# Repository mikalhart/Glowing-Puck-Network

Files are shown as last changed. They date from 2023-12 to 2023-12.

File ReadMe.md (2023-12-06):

# The Glowing Puck

Glowing Pucks are coaster-sized art objects ostensibly built to decorate tables at a celebration dinner, but with a few surprises for the guests.  They are small, circular resin creations made of dried English wildflowers embedded in an epoxy disc, encased in a 3D-printed shell.

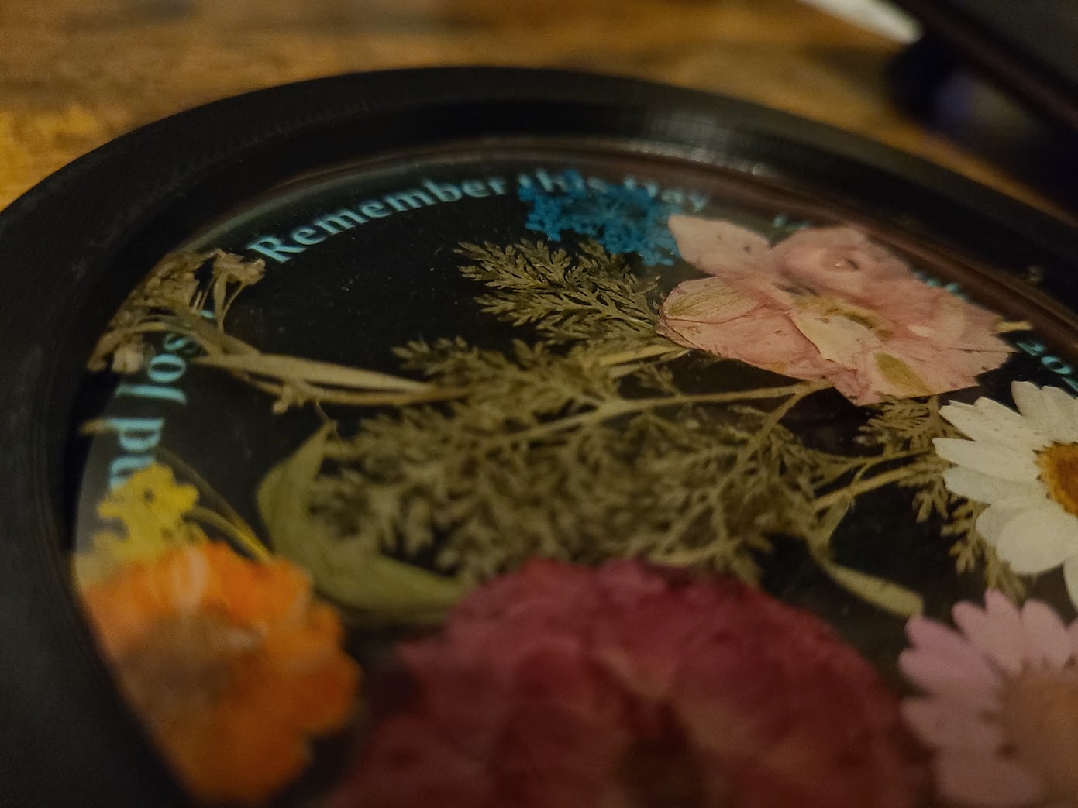
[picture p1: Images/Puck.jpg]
Pre-glow Puck


## A Surprise

At a 'significant moment' in the dinner (e.g. when bride and groom reappear), the Pucks around the room mysteriously begin to glow: first one... then two... then eventually all of them.  Soon the whole room is illuminated with bright, colorful swirling light!

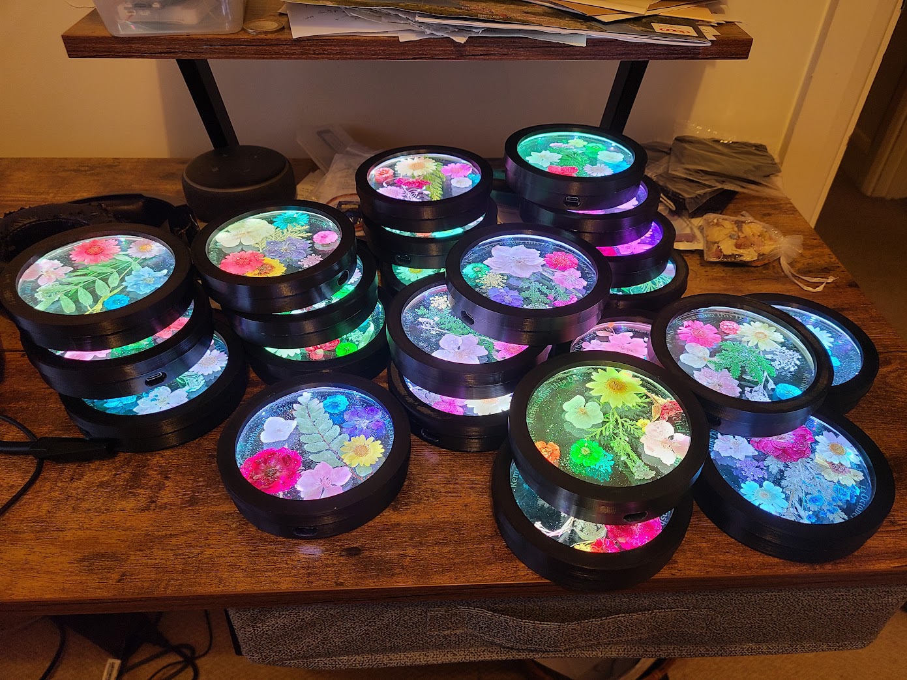
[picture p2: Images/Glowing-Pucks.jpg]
Glowing Pucks


## The Glow Explained

A speaker suddenly stands.  She explains to the murmuring guests that the Glow is intended to symbolize the love and support we share for the new couple on the threshold of their married life.  It celebrates that we are a loving people who came together on this memorable day to wish them happiness.

## A New Surprise: More Glows to Come

As the dinner progresses the Pucks continue to Glow cheerily, but eventually they fade and resume their inert state. The speaker rises once again.  The initial phase has ended, she explains. In preparation for the next, we are to take our Pucks home, join them to our house WiFi, and place them in a prominent location.

We learn that each of us has been granted the power to recreate the wedding Glow by touching two brass discs hidden on the Puck's underside.  A so-activated Puck sends a quiet invitation to its siblings around the world to join in a new Glow. Touching the brass discs triggers a global chorus of light and remembrance.

It's a beautiful way for us to commemorate the wedding and keep its memory fresh and alive.  It's how we'll reach out and say, "we remember you, and we remember this day!"

## One Final Surprise

The Pucks have one more surprise in store.  Every year on the date of the wedding anniversary, they perform a special celebration Glow that lasts the **entire day**.

## Theory of Operation

### At the Dinner

The Pucks are built to operate in two different modes.  As table ornaments, they are mostly asleep/inert, running off battery power and invisibly awakening every minute to check for special instructions.

At the predetermined time, the speaker (or someone in the audience) quietly enables a special 2.4GHz "Hot Spot" on her smartphone.  This is the signal to begin.  When the Pucks detect the new WiFi SSID **wedding-fireworks**, they start the spectacular celebration Glow.

The Pucks Glow for as long as that special WiFi SSID is enabled.  Once it disappears, they resume their semi-dormant state.

### At Home

After the Pucks have been distributed to their new homes, they must be connected to WiFi to sync with the 'Glow network'.  At this point they will be kept more or less always plugged in.

Teaching a Puck its new home's WiFi credentials involves putting it into "WiFi Training Mode" and configuring it with a cell phone or tablet. Instructions can be found in the [WiFi Training](WiFi-Training.md) document.

Once set up, a Puck at home wakes whenever its brass discs are touched.  This triggers a glow that cascades around the world, with a limit of one activation per Puck per day.

A Puck at home also wakes each minute to check whether any other Puck on the network has activated a Glow.  If so, it joins in!

## Build Guide

If you'd like to build your own Glow Pucks, consult the [Build Guide](Build-Guide.md).

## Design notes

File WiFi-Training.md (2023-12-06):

# Instructions for connecting the Puck to WiFi

To join the Glow network, each Puck must connect to its new owner's WiFi. It's probably best to provide the guests an instruction sheet when you hand them out, explaining how this is done.

## WiFi Training Instructions

At home, plug your new Puck in and teach it how to connect to your WiFi by putting it into **WiFi Training Mode**.

1. Gently press and hold the two brass discs for about six seconds.  Release when the Puck begins to pulse blue.

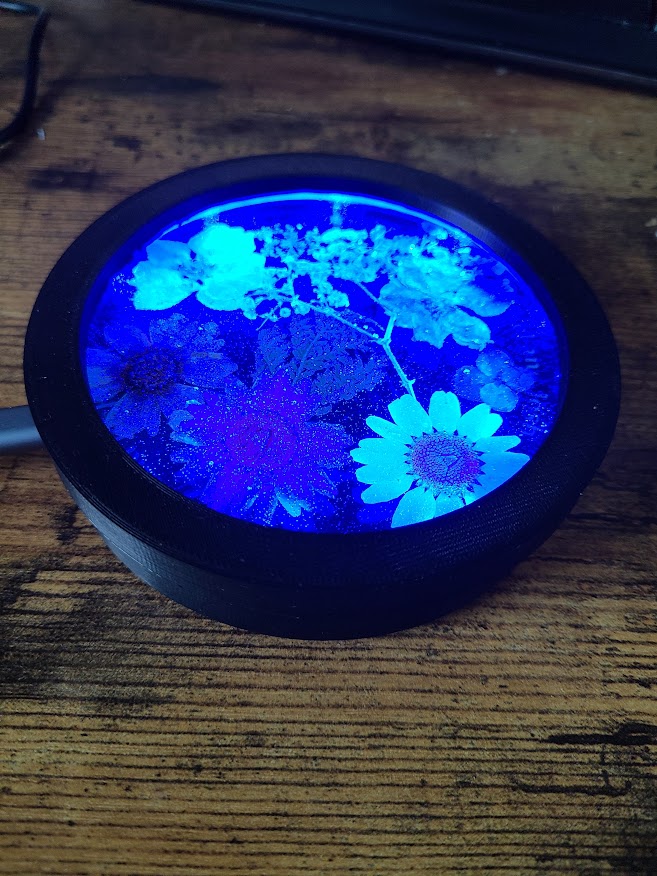
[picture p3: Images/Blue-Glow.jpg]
Blue Glow
    

1. On your phone or tablet, hunt for the newly-created WiFi network **Wedding-Puck**.  Connect to it.  (This network isn't connected to the internet, and on certain phones you may have to acknowledge that fact.)

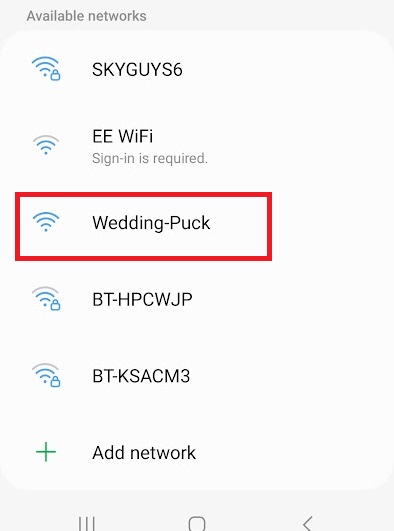
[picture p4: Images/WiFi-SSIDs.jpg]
WiFi SSIDs
    

1. In your phone's camera app, scan the QR code below, or simply open a browser and type <http://192.168.4.1> in the URL bar.

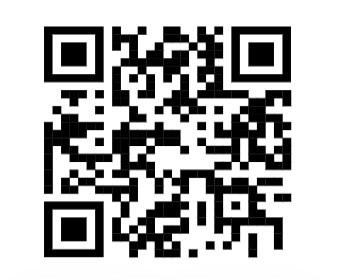
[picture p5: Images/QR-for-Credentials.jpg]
QR for Credentials
    

1. This brings up a page where you can enter your WiFi credentials. Fill in the page with your home WiFi name (SSID) and password and press **Submit**.  The Puck will store this info to connect to your WiFi.

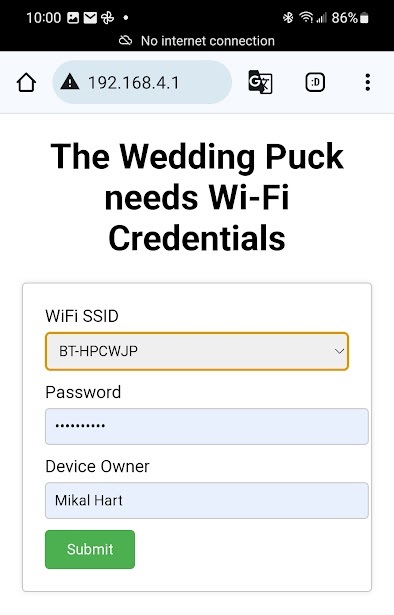
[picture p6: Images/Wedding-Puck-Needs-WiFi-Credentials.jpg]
Enter Credentials
    

At this point, WiFi Training ends, and your Puck is connected.  (It may immediately begin a celebration Glow in recognition that someone else has previously activated theirs.)

Keep your Puck plugged in.  Repeat steps 1-5 if you change location or WiFi credentials.

Whenever your Puck is dark, activate your own Glow by gently touching the two brass discs.

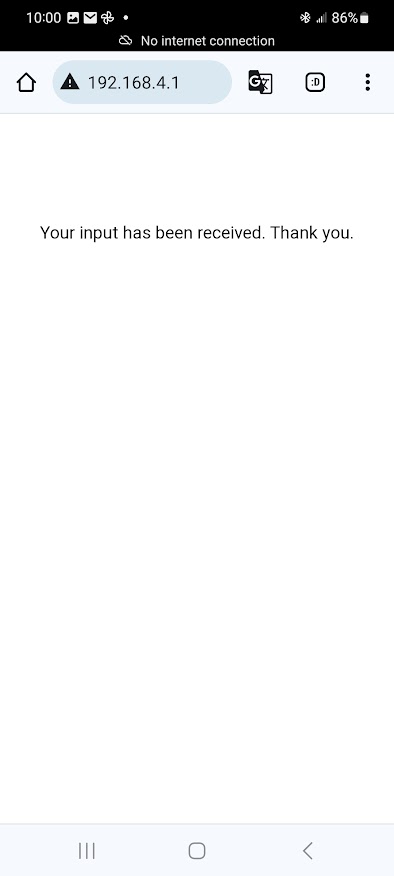
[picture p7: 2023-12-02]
Images/Your-Input-Has-Been-Received.jpg

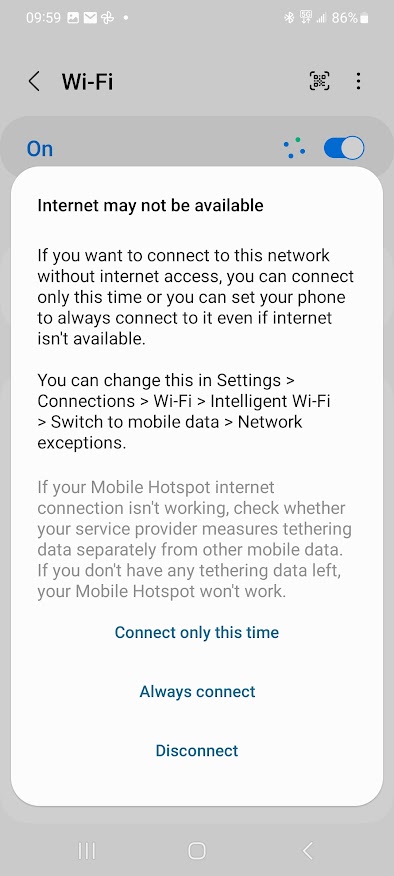
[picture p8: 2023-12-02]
Images/Internet-May-Not-Be-Available.jpg

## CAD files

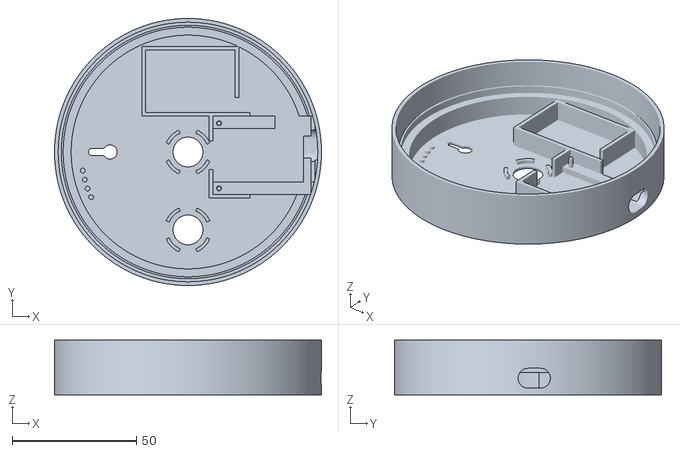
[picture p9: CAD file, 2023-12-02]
Collateral/Case-bottom.stl
107.4 x 107.4 x 22.0

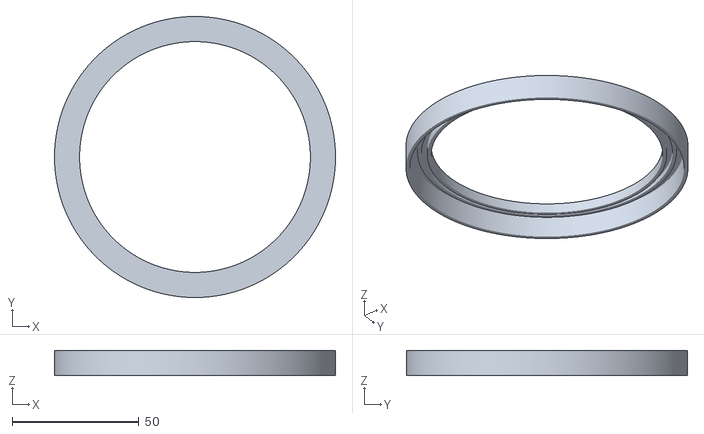
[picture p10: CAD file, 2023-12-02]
Collateral/Case-top.stl
110.8 x 110.8 x 10.0

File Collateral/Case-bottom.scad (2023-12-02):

use <Case-modules.scad>
Bottom();

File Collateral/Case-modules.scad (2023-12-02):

$fa = 1;
$fs = 0.5;
VERSION = 4;
TOPVERSION = 2;
WALL = 1.5;
DEPTHBASE = 1;
COASTERDIAM = 100;
LEDBANDTHICKNESS = 2;
FUDGE = 0.2;
USB_OFF_FROM_CENTER = 3.8;
USB_RECESS = 4;
USB_WIDTH = 9;
USB_HEIGHT = 7.6;
USB_DEPTH = 2;
DEPTHBATTERY = 9;
DEPTHSHIELD = 4;
PLATFORMDEPTH = 3.5;
PCBTHICKNESS = 2.2;
BOARDWALLDEPTH = 9; // 10; // high enough to hold the board, support coaster
LEDBANDWIDTH = 13;
LEDRETAINERDEPTH = BOARDWALLDEPTH + 3;
RIMWALLDEPTH = BOARDWALLDEPTH + LEDBANDWIDTH;

TOPRIMWALLDEPTH = 10;
SPECIALOFFSET = 2.5; // A northward bias for the compartments and USB hole to avoid leaks

D0 = COASTERDIAM - 4 * WALL;    // inside the edge of the coaster
DZ = D0 - 3;                    // inside-most rim of lid
D1 = COASTERDIAM + 2 * FUDGE;   // just outside the edge of the coaster
D1a = D1 + WALL;                // coaster retainer goes from D1 to D1a
D2 = D1 + 2 * LEDBANDTHICKNESS; // outside LEDs, inside of exterior wall
D3 = D2 + 2 * WALL;             // outside exterior wall
D4 = D3 + 2 * FUDGE;            // inside lid wall
D5 = D4 + 2 * WALL;             // outside lid wall

module Bottom()
{
  difference()
  {
    union()
    {
      BottomBase();
      compartments();
      difference() { supportrim(); compartments(true); }
      difference() { outerwall(); compartments(true); }
    }
    USBHole();
  }
}

module Top()
{
  translate([0, 0, 40])
  rotate([0, 180, 0])
  {
    color("red") topouterwall();
    color("green") topinnerwall1();
    color("purple") topinnerwall2();
    color("yellow") topflattop();
    // topstackingwall(); 
  }
}

module BottomBase()
{
  difference() 
  { 
    cylinder(h=DEPTHBASE, d = D3); 
    MountingHole(DEPTHBASE); 
    brassbutton(-D0/3, 0, 90, true);
    brassbutton(0, 0, 0, true);
  } // floor

  brassbutton(-D0/3, 0, 90, false);
  brassbutton(0, 0, 0, false);

  // Version indicators
  for (i=[1:VERSION])
    rotate([0, 0, 185 + 5 * i])
      translate([D0 / 2 - 4, 0, 0])
        cylinder(h=DEPTHBASE + 1, d = 2);
}

module pieSlice(a, r, h)
{
  // a:angle, r:radius, h:height
  rotate_extrude(angle=a) square([r,h]);
}

module brassbutton(x, y, angle, negative = false)
{
  BRASSDIAM = 16;
  BRASSDEPTH = 1;
  LIPWIDTH = 2;
  BRACKETDEPTH = 2.5;
  rotate([0, 0, angle])
  translate([x, y, 0])
  {
    if (negative)
    {
      cylinder(h=BRACKETDEPTH, d=BRASSDIAM - 2 * LIPWIDTH);
    }
    else
    {
      difference()
      {
        cylinder(h=BRACKETDEPTH, d=BRASSDIAM+2*WALL);
        cylinder(h=BRACKETDEPTH, d=BRASSDIAM+2*FUDGE);
        for (i=[0:90:270])
        rotate([0, 0, i-45/2])
          pieSlice(45, BRASSDIAM+2*WALL, BRACKETDEPTH);
      }
    }
  }
}

LIPDEPTH = 2.5; // for stacking coasters
module topouterwall()
{
  difference()
  {
    cylinder(h=TOPRIMWALLDEPTH, d = D5);
    
    // We'll make the removed cylinder taper slightly inward
    cylinder(h=TOPRIMWALLDEPTH+0.1, d1 = D4 - 2 * FUDGE, d2 = D4);
  }
}

// Not used
module topstackingwall()
{
  translate([0, 0, -LIPDEPTH])
  difference()
  {
    cylinder(h=LIPDEPTH, d = D5);
    cylinder(h=LIPDEPTH, d = D4);
  }
}

INNERWALLDEPTH1 = 2;
INNERWALLDEPTH2 = 3;
module topinnerwall1()
{
  OUTER = D1a - FUDGE;
  INNER = OUTER - 2 * WALL;
  DEPTH = DEPTHBASE + INNERWALLDEPTH1;
  difference()
  {
    cylinder(h=DEPTH, d = OUTER);
    cylinder(h=DEPTH+0.1, d = INNER);
  }
}

module topinnerwall2()
{
  OUTER = D0;
  INNER = DZ;
  DEPTH = DEPTHBASE + INNERWALLDEPTH2;
  difference()
  {
    cylinder(h=DEPTH, d = OUTER);
    cylinder(h=DEPTH+0.1, d = INNER);
  }
}

module topflattop()
{
  difference()
  {
    cylinder(h=DEPTHBASE, d = D5);
    cylinder(h=DEPTHBASE+0.1, d = DZ);
  }
  DEP = 1;
  DIA = 2;
  if (0) for (i=[1, TOPVERSION])
  {
    rotate([0, 0, 180 + 5 * i])
    translate([(D5 + D0) / 4, 0, -DEP])
    cylinder(h = DEP, d = DIA);
  }
}

module outerwall()
{
  difference()
  {
    cylinder(h=RIMWALLDEPTH, d = D3);
    cylinder(h=RIMWALLDEPTH, d = D2);
  }
}

// Shelf that supports coaster and brackets it
module supportrim()
{
  difference()
  {
    cylinder(h=BOARDWALLDEPTH, d = D2);
    cylinder(h=BOARDWALLDEPTH, d = D0);
  }

  // LED retainer
  difference()
  {
    cylinder(h=LEDRETAINERDEPTH, d = D1a);
    cylinder(h=LEDRETAINERDEPTH, d = D1);
  }
}

module compartments(negative = false)
{
  BOARDWIDTH = 39.5; // 39.1; // 40.1;
  BOARDHEIGHT = 31.5;
  CONNECTORWIDTH = 8;

  PILLAROFFSETX = 2.5;
  PILLAROFFSETY1 = 2.4;
  PILLAROFFSETY2 = 2.9;
  PILLARDIAMTOP = 1.7; // 1.7;
  PILLARDIAMBASE = 2.0; // 1.7;
  PILLARDEPTH = 4.0; // 3.0;

  BATTERYWIDTH = 36.0; // 37.0; // 38.0;
  BATTERYHEIGHT = 25.0; // 25.5; // 26.0;
  BATTERYDEPTH = 8;

  CABLEEXTRA = 27;
  CABLEWIDTH = 6;

  RWALL = D1 / 2 - .7;
  x0 = RWALL - BOARDWIDTH - WALL;
  x1 = x0 + WALL;
  x1a = x1 + 15;
  x2 = x1 + 25;
  x3 = RWALL;
  x4 = x3 + WALL;
  
  y0 = -BOARDHEIGHT / 2 - USB_OFF_FROM_CENTER - WALL + SPECIALOFFSET;
  y1 = y0 + WALL;
  y3 = BOARDHEIGHT / 2 - USB_OFF_FROM_CENTER + SPECIALOFFSET;
  y2 = y3 - CONNECTORWIDTH;
  y4 = y3 + WALL;
  
  a0 = x0 - CABLEEXTRA;
  a1 = a0 + WALL;
  a2 = a1 + BATTERYWIDTH;
  a3 = a2 + WALL;
  
  b0 = y3;
  b1 = b0 + WALL;
  b2 = b1 + BATTERYHEIGHT;
  b3 = b2 + WALL;

  if (negative)
  {
    translate([x1, y1, 0])
      cube([x3-x1, y3-y1, LEDRETAINERDEPTH]);
    SWITCHOFFSET = 5;
    translate([x3, y1 + SWITCHOFFSET, 0])
      cube([x4-x3, y3-y1-SWITCHOFFSET, LEDRETAINERDEPTH]);
  }
  else
  intersection()
  {
    union()
    {
      // Board stuff
      translate([x0, y3-10, 0]) // top of left wall
        cube([x1-x0, 10, BOARDWALLDEPTH]);
      translate([x0, y1, 0]) // bottom of left wall
        cube([x1-x0, 10, BOARDWALLDEPTH]);
      translate([x0, y0, 0]) // bottom wall
        cube([x1a-x0, y1-y0, BOARDWALLDEPTH]);
      translate([x0, y3, 0]) // top wall
        cube([x1a-x0, y4-y3, BOARDWALLDEPTH]);
      translate([x3, y0, 0]) // right wall
        cube([x4-x3, y4-y0, PLATFORMDEPTH + PCBTHICKNESS/*BOARDWALLDEPTH*/]);

      translate([x1, y3-5, 0]) // platform 1 (upper left)
        cube([x2-x1, 5, PLATFORMDEPTH]);
      translate([x1, y1, 0]) // platform 2 (lower left)
        cube([x3-x1, 5, PLATFORMDEPTH]);
      translate([x3-3, y1, 0]) // platform 3 (right)
        cube([3, y2 - y1, PLATFORMDEPTH]);
      translate([x1 + PILLAROFFSETX, y1 + PILLAROFFSETY1, PLATFORMDEPTH]) // pillar 1
        cylinder(h = PILLARDEPTH, d1 = PILLARDIAMBASE, d2 = PILLARDIAMTOP);
      translate([x1 + PILLAROFFSETX, y3 - PILLAROFFSETY2, PLATFORMDEPTH]) // pillar 2
        cylinder(h = PILLARDEPTH, d1 = PILLARDIAMBASE, d2 = PILLARDIAMTOP);
      
      // Battery stuff
      translate([a0, b0, 0]) // left wall
        cube([a1-a0, b3-b0, BOARDWALLDEPTH]);
      translate([a0, b0, 0]) // bottom wall
        cube([a3-a0, b1-b0, BOARDWALLDEPTH]);
      translate([a0, b2, 0]) // top wall
        cube([a3-a0, b3-b2, BOARDWALLDEPTH]);
      translate([a2, b1 + CABLEWIDTH, 0]) // right wall
        cube([a3-a2, b3-(b1 + CABLEWIDTH), BOARDWALLDEPTH]);
    }
    cylinder(h=BOARDWALLDEPTH, d = D3);
  }
}

module USBHole()
{
  USB_HOLE_WIDTH = USB_WIDTH + 2 * 2;
  USB_HOLE_HEIGHT = USB_HEIGHT + 2 * 3 + WALL;
  USB_HOLE_DEPTH = USB_DEPTH + 2 * 2 + 2;
  RWALL = COASTERDIAM / 2;

  translate([RWALL - USB_HOLE_HEIGHT/2 + 0.2, 0 - USB_HOLE_WIDTH / 2 + SPECIALOFFSET, PLATFORMDEPTH + PCBTHICKNESS + USB_DEPTH / 2 - USB_HOLE_DEPTH / 2/*USB_DEPTH / 2 */])
  rotate([0, 0, 90])
  rotate([90, 0, 0])
  union()
  {
      RADIUS = USB_HOLE_DEPTH / 2;
      translate([RADIUS, RADIUS, 0])
          cylinder(h = USB_HOLE_HEIGHT, d = USB_HOLE_DEPTH);
      translate([RADIUS, 0, 0]) 
          cube([USB_HOLE_WIDTH - USB_HOLE_DEPTH, USB_HOLE_DEPTH, USB_HOLE_HEIGHT], false);
      translate([USB_HOLE_WIDTH - USB_HOLE_DEPTH + RADIUS, RADIUS, 0])
          cylinder(h = USB_HOLE_HEIGHT, d = USB_HOLE_DEPTH);
  }
}

module MountingHole(depth)
{
  HEAD4DIAM = 5.48;
  SHAFT4DIAM = 2.74;

  BIGDIAM = HEAD4DIAM + FUDGE;
  LITTLEDIAM = SHAFT4DIAM + FUDGE;

  translate([-D0/3, 0, 0])
  rotate([0, 0, 90])
  {
    cylinder(depth, d = BIGDIAM);
    translate([-LITTLEDIAM / 2, 0, 0]) 
      cube([LITTLEDIAM, BIGDIAM/2 + 3 * LITTLEDIAM / 2, depth], center = false);
    translate([0, BIGDIAM/2 + 3 * LITTLEDIAM / 2, 0])
      cylinder(depth, d = LITTLEDIAM);
  }
}

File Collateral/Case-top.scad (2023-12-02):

use <Case-modules.scad>
Top();

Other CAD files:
Collateral/Case.scad

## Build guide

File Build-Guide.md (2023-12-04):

# Building Your Own Glowing Pucks

It's not too hard to build your own Glowing Pucks.  There's very little electronic assembly: only 5 wires to be soldered.  No small-pitch stuff.

The Puck shell needs to be 3D printed.  Other than that, the hardware assembly is trivial.

Software install shouldn't be too tricky for anyone who has done any Arduino programming, though you'll need to get a (free) account at HiveMQ to support the MQTT traffic.  Other MQTT brokers would probably work fine as well.

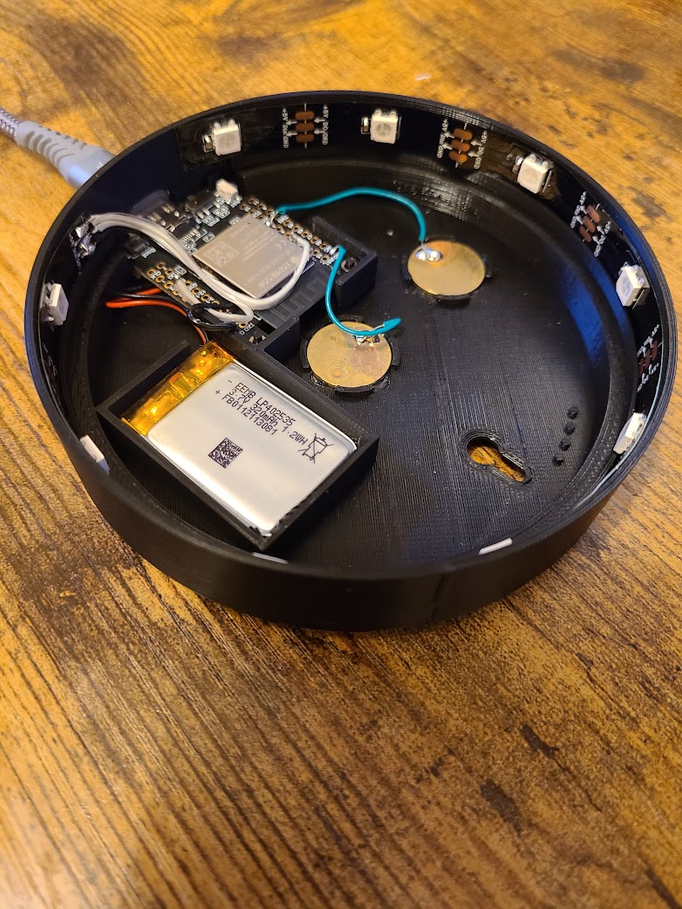
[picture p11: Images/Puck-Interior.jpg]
The interior of a Puck


## Materials

You'll need to procure a handful of inexpensive electronic and hardware items to build this project.

### Electronic Components

- LilyGo ESP32 [T7-S3 Development Board](https://www.lilygo.cc/products/t7-s3) - the brains behind the device
- 9 [WS2812-B LEDs](https://www.aliexpress.com/item/2036819167.html) in 30/meter spacing - these are embedded in the shell and illuminate the epoxy coaster from the side
- 2 16mm [brass stamping blanks](https://www.aliexpress.com/item/32716955260.html) - the touch "buttons" that turn the device on
- 320mah [402535 LiPo Battery](https://www.amazon.co.uk/dp/B08HD1N273) - **WARNING: The 1.2mm connector needs polarity reversal**
- 3-wire [ribbon cable](https://www.amazon.co.uk/dp/B09R42ZGQD) - to connect the microcontroller to the LED strip
- 2 26-gauge [solid-core wires](https://www.amazon.co.uk/sourcing-map-Electrical-High-Temperature-Manipulator/dp/B0C6FDQ6K9) - to connect the brass discs to the microcontroller
- [USB-C Cable](https://www.amazon.co.uk/dp/B0BPH67J4X) - for charging the device

### Hardware Components

- 3D-printed Coaster [lid](Collateral/Case-top.stl) and [base](Collateral/Case-bottom.stl).  (SCAD source: [lid](Collateral/Case-top.scad), [base](Collateral/Case-bottom.scad))
- 10cm diam x 1cm deep Epoxy Coaster - I love [these](https://www.etsy.com/uk/listing/1048533995/purple-floral-handmade-resin-coasters?variation0=2108656922), but any clear coaster with these dimensions should do
- 10cm diameter background [background](Collateral/Puck-Background.png) ([svg](Collateral/Puck-Background.svg))
- 4 stick-on [rubber feet](https://www.amazon.co.uk/gp/product/B08QHZ1SW4)

### Software Components

- [Wedding-Puck.ino](Wedding-Puck.ino) Arduino sketch
- Several Arduino Libraries
  - [Adafruit NeoPixel](https://github.com/adafruit/Adafruit_NeoPixel) - to drive the LEDs
  - WiFiClientSecure (built-in) - for interacting with MQTT broker
  - [PubSubClient](https://github.com/knolleary/pubsubclient) - for interacting with MQTT broker
  - [ESPAsyncWebServer](https://github.com/me-no-dev/ESPAsyncWebServer) - for WiFi Training mode
  - [AsyncTCP](https://github.com/dvarrel/AsyncTCP) - for WiFi Training mode
  - [ArduinoJson](https://github.com/bblanchon/ArduinoJson) - for saving WiFi credentials

## Assembling the Electronics

1. **Cut LED strip**.  Cut a strip of 9 LEDs from the WS2812B roll.  At 30/meter spacing, this gives just about the right length to surround the 10cm diameter coaster.

1. **Solder LED Strip**.  Cut and strip about 6cm of the ribbon cable.  Solder one end of the ribbon cable to the 3 inputs om the LED strip and the other end to the LilyGo T7-S3 as follows:

    - **LED GND** <--> **T7 GND**
    - **LED +5V** <--> **T7 +5V**
    - **LED Din** <--> **T7 pin 18**

1. **Solder Brass Discs**. Cut and strip about 3-4cm of the solid-core wire.  Solder one end of each wire to a brass disc.  You'll have to apply the iron for a long time to get the discs hot enough to properly bond with the solder.  Be careful!  Don't burn yourself on the hot disc!  Solder one wire to T7 GND and the other to the T7 touch pin 5.

    - **Centre Brass Disc** <--> **T7 GND**
    - **Edge Brass Disc** <----> **T7 pin 5**

1. **Hook up battery**.  Insert the battery into the T7 connectoor.  **NOTE**: If you buy the variant of the [402535 LiPo battery](https://www.amazon.co.uk/dp/B08HD1N273) that I sourced on [Amazon](https://www.amazon.co.uk/dp/B08HD1N273), it is the **WRONG POLARITY**.  You'll need to make an easy [polarity adjustment](https://youtu.be/za-azgbZor8?si=B9gw-FfFPbaVmNWF) before you use it with the T7-S3.  Make **sure** the battery's red wire matches up with the **+** terminal on the T7.

## Assembling the Hardware

1. **Print Case**.  Print the [top](Collateral/Case-top.stl) and [bottom](Collateral/Case-bottom.stl) coaster shells.  I've had good luck with black PLA, but I imagine any material would do.

1. **Mount Circuitry**. Snap the T7 and the battery into their respective compartments in the shell base.

1. **Mount LED strip**. Insert the LED strip into its grooved slot around the perimeter of the base, with the LEDs facing inward.  No need to remove the adhesive on the back of the strip: it's not going anywhere.  The epoxy coaster and the assembly will keep it firmly in place.

1. **Glue Discs**. Apply a bit of super glue - I find the gel variant works great - around the rim of the round compartments on the bottom, and glue the brass discs into place.

1. **Create Backdrop**.  Cut a 10cm circle from a bit of black paper or cardstock to use as a backdrop.  You'll insert it into the shell base, underneath the epoxy coaster.  Optionally, draw a design in gold or coloured pen that can be seen through the transparent bits.  (I created a [design](Collateral/Puck-Background.png) in Inkscape that I printed on a 5x7" photo printer.  This worked rather well.)
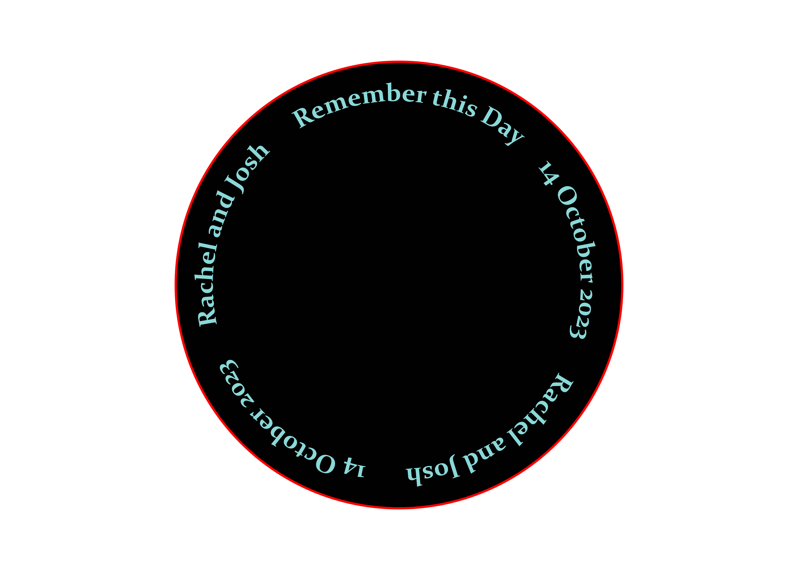
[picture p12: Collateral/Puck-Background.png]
Puck Backdrop


1. **Install Software and Test**. Before you permanently glue down the electronics, now would be a good time to install the software components and test the hardware, in case you need to do any rework.

1. **Hot Glue Components**.  Apply just enough glue to hold the T7 and battery firmly in place.  Hot glue works great here.  Put some on the brass discs, too, to help stabilize them.

1. **Insert Backdrop and Coaster**. Insert the backdrop and the epoxy coaster into the assembly.  If the coaster is not perfectly round, you may have to use a small screwdriver to pry it into place.

1. **Finish Assembly**. Press the shell lid down onto the assembly.  It's tapered to have a reasonably nice press fit, but you might consider applying a dab of hot glue here.

1. **Attach Feet**.  Affix four evenly-spaced rubber feet to the base.

## Software Installation

1. Get a free [Hive MQ](https://www.hivemq.com/company/get-hivemq/) account.  We'll use their MQTT brokerage service to post and read "Glow" messages from Pucks.  Hive has a nice free level that supports up to 100 devices.

1. Create a new MQTT broker **Cluster** in your Hive MQ account.  Write down the server URL and the user credentials for your Cluster: you'll need to insert these into the sketch shortly.

1. Install **Arduino**, the **ESP32 plug-in**, and the required libraries:

    - [Adafruit NeoPixel](https://github.com/adafruit/Adafruit_NeoPixel)
    - WiFiClientSecure (built-in)
    - [PubSubClient](https://github.com/knolleary/pubsubclient)
    - [ESPAsyncWebServer](https://github.com/me-no-dev/ESPAsyncWebServer)
    - [AsyncTCP](https://github.com/dvarrel/AsyncTCP)
    - [ArduinoJson](https://github.com/bblanchon/ArduinoJson)

1. Open the [Wedding-Coaster.ino](Wedding-Coaster.ino) sketch and configure it with these settings for the LilyGo T7.
    - Board = **ESP32S3 Dev Module**
    - PSRAM = **OPI**
    - Flash Mode = **QIO 80MHz**
    - Flash Size = **16MB**
    - USB Mode = **Hardware CDC and JTAG**
    - USB CDC On Boot = **Enabled**
    - Partition Scheme = **Minimal SPIFFS (1.9MB APP with OTA/190KB SPIFFS)**.

1. At the top of the [Wedding-Coaster.ino](Wedding-Coaster.ino) sketch, customize the strings as appropriate to your configuration:

    - Enter the **MQTT server and login credentials** for your Hive MQTT broker.
    - Set **default WiFi Credentials** if you want to use the Puck's auto-provisioning feature (optional).
    - Customize the **WiFi Training** strings, displayed when the Puck goes into WiFi training mode (optional).
    - Set wedding **anniversary** information if you want to do the special Anniversary Glow (optional).

The code you'll need to edit is this bit:

```C++
        // Hive MQ credentials for MQTT broker
        #define mqttServer "xxxxxxxxxxxxxxxxxxxxxxxxxxxxxxxx.xx.xx.hivemq.cloud"
        #define mqttUser ".........."
        #define mqttPass ".........."

        // Optional Auto-provisioning customization
        #define DEFAULT_WIFI_SSID ".........."
        #define DEFAULT_WIFI_PASS ".........."
        #define DEFAULT_WIFI_OWNER "........."

        // WiFi Training strings (customize here)
        #define WIFI_HOST_NAME "Wedding-Puck"
        #define ACK_MESSAGE "<p>Your input has been received. Thank you.</p>"
        #define ACK_PAGE_TITLE "The Wedding Puck"

        // Optional Anniversary celebration info
        // #define WEDDING_DAY 14
        // #define WEDDING_MONTH 10
        // #define WEDDING_YEAR 2023
```

Finally, install and run [Wedding-Coaster.ino](Wedding-Coaster.ino) on each coaster.

## General Testing

1. **Touch Test.** Once the sketch has been successfully installed, the first test is to touch the brass discs.  The LEDs should dimly light in an orange-ish glow that indicates the Puck is trying to connect.  If you don't see any light, check the wiring to the LED strip and to the brass discs. Examine the debug output in the Serial console.  Because WiFi is not yet configured, the LEDs should eventually pulse purple and fade to black.
1. **Externally-triggered 'Glow' Test.**  On a phone with a 2.4GHz WiFi Hotspot feature, create a Hotspot called **wedding-fireworks**.  Within a minute or so, the Puck should start Glowing until the Hotspot expires or is disabled.
1. **WiFi Training Test.** Set up WiFi via either WiFi Training or Auto-provisioning. (See below.)
1. **Locally-triggered 'Glow' Test.** Now that WiFi is available, test a local 'Glow' by touching the brass discs. If WiFi has been correctly set up, this should initiate a five-minute light show.  If you get a short purple pulsing instead, the WiFi connection likely failed - probably because the credentials were not properly configured.  Red pulsing means things are working properly, but you attempted a second Glow too quickly.
1. **Quick Trigger Test.** Verify that a quick second Glow attempt does indeed trigger the red pulsing error indication.
1. **Multi-Puck Test.** If you have built more than one Puck, verify that 'Glowing' one triggers the others.  If it doesn't work, make sure they have all been correctly connected to WiFi.

## WiFi Training Testing

Once the Pucks have been distributed to your guests, they need to be connected to WiFi. The new owners do this by putting the Puck through **WiFi Training Mode**. Test this before distributing! Detailed instructions can be found [here](WiFi-Training.md), but here's the basic idea:

1. Press the brass discs for 6 seconds until the Puck pulses blue.  The Puck stays in WiFi Training mode for up to 5 minutes.
1. Verify on your cell phone/tablet that WiFi Hotspot **Wedding-Puck** is available.  Connect to it.
1. Point your phone's browser to the WiFi configuration page at <http://192.168.4.1>.  This should bring up a form where you can enter your credentials.  Verify that the page looks right.  (You can customize its look in your sketch.)
1. Verify that once you "submit" your credentials, the Puck operates properly.  It should now Glow when triggered by another WiFi-connected Puck or when you touch the brass discs.
1. Once you are satisfied, you can erase your own WiFi credentials from the Puck's storage by **deprovisioning**.  (See below.)

## Auto-Provision/Deprovision Testing

If you have set **DEFAULT_WIFI_SSID** and **DEFAULT_WIFI_PASS** in your sketch, you can use a feature called "auto-provisioning" to temporarily set your own WiFi credentials on the Puck.  Initially, Pucks can't log into WiFi, because no credentials are yet stored in the local flash.  But, for testing purposes, you can temporarily store the DEFAULT values you've entered using one of these two techniques:

1. Create 2.4GHz Hotspot **wedding-provision** on a phone or tablet. This should provision default WiFi credentials for *all* active Pucks within range of the phone within 90 seconds. Each Puck will glow green when it's been provisioned.  OR,
2. Press and hold a Puck's brass discs for about 20 seconds... until it glows green.  This provisions a single puck.

Provisioning saves you the hassle of having to perform WiFi Training on each puck when you're testing.

Once you are satisfied everything is working, you can erase all saved credentials from storage by *deprovisioning*.  Create a 2.4GHz Hotspot **wedding-deprovision** and leave it active for a couple of minutes.

## Hotspot commands

To review, here are the secret puck commands you can issue by setting up a 2.4GHz Hotspot on your phone.  Note that the ESP32 processor is only capable of 2.4GHz band WiFi, so certain iPhones, which default to 5GHz, may not work without changing some settings.

- **wedding-fireworks** ----> do the wedding dinner glow
- **wedding-provision** ----> provision all pucks with the default SSID/pass
- **wedding-deprovision** --> erase all WiFi credentials from all pucks

## T7-S3 Wiring

Wiring for this project is simple.  Here's a reminder chart.

| Conn A | Conn B |
| --- | --- |
| T7 GND | Centre Brass Disc |
| T7 GPIO5 | Edge Brass Disc |
| T7 GND | LED Strip GND |
| T7 GPIO18 | LED Strip Din |
| T7 5V | LED Strip 5V |

## Strategy

The Puck spends most of its time asleep, waking every minute or when its brass discs are touched.  When it wakes, it does two things:

1. It tries to connect to the local WiFi (if credentials have been configured) to check whether any new messages have been published on the MQTT broker's */devices/glow* topic.  If there is a new message, the device performs a 5-minute Glow. If it was awakened by a touch, it *publishes* an MQTT notification to alert the other Pucks before performing the Glow.
1. Next, it scans the available WiFi SSIDs to see if any special "Hotspot commands" (see above) have been issued.  If the **wedding-fireworks** SSID is seen, it performs a 1-minute Glow repeatedly for as long as the SSID is present.

## Detailed Algorithm

At wake-up, the device follows this algorithm:

- If voltage is too low, then flash red and go back to sleep.
- If wake is from touch, do the orange/brown "I'm thinking" pattern.
  - If touch lasts >6 seconds, transition to blue and do **WiFi Training**.
  - If touch lasts >20 seconds, transition to green and **auto-provision** default WiFi SSID/password.
- If it's the anniversary of the wedding, do a special 24-hour "Anniversary Animation".
- Try to connect to Wifi.
  - If successful, action depends on whether device has ever been "touched".
    - Touched?
      - If it's been > 23 hours since the last locally-initiated Glow, tell MQTT broker that we are triggering a new one!
      - If not, give the red 'error' signal.
    - Not touched?
      - Check MQTT broker for new messages.  If broker says that another Puck has recently initiated a Glow, do a 5-minute one in response.
  - If WiFi connection fails and the device was started by a touch, give the pulsing purple error signal to indicate that new WiFi credentials are likely needed.
- Look for special "Hotspot" SSID commands.
  - **wedding-fireworks** - do a Glow
  - **wedding-provision** - provision default WiFI SSID/password
  - **wedding-deprovision** - erase any WiFi credentials
- Fade to black
- Sleep for 60 seconds
- Repeat

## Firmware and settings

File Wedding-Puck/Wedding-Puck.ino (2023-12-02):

#include <Adafruit_NeoPixel.h>
#include <WiFi.h>
#include <esp_adc_cal.h>
#include <sntp.h>
#include <esp_crt_bundle.h>
#include <ssl_client.h>
#include <WiFiClientSecure.h>
#include <PubSubClient.h>

#include "WiFi-Manager.h"

#if __has_include("private.h")

#include "private.h" // (you can put the information below in a separate header)

#else

// Hive MQ credentials for MQTT broker
#define mqttServer "xxxxxxxxxxxxxxxxxxxxxxxxxxxxxxxx.xx.xx.hivemq.cloud"
#define mqttUser ".........."
#define mqttPass ".........."

// Optional Auto-provisioning customization
#define DEFAULT_WIFI_SSID ".........."
#define DEFAULT_WIFI_PASS ".........."
#define DEFAULT_WIFI_OWNER "........."

// WiFi Training strings (customize here)
#define WIFI_HOST_NAME "Wedding-Puck"
#define ACK_MESSAGE "<p>Your input has been received. Thank you.</p>"
#define ACK_PAGE_TITLE "The Wedding Puck"

// Optional Anniversary celebration info
#define WEDDING_DAY 14
#define WEDDING_MONTH 10
#define WEDDING_YEAR 2023

// These are the hotspot names you can use to secretly signal pucks to glow (or provision, etc)
#define FIREWORKS_SSID "wedding-fireworks"
#define PROVISION_SSID "wedding-provision"
#define DEPROVISION_SSID "wedding-deprovision"

// After initiating a glow, you have to wait 23 hours to be eligible to do it again
#define SECONDS_BETWEEN_GLOWS (23 * 60 * 60)

// The length of a "glow" (5 minutes)
#define FIREWORKS_LENGTH_SECONDS (5 * 60)

#endif

// Pin assignments
#define NEOPIXELPIN 18
#define BATTERYPIN 2
#define TOUCHPIN 5
#define LEDPIN 17

// ESP32-S3 touch pin sensitivity
#define TOUCH_THRESHOLD 30000

// How many NeoPixels are attached to the ESP32?
#define NUMPIXELS 9

Adafruit_NeoPixel pixels(NUMPIXELS, NEOPIXELPIN, NEO_GRB + NEO_KHZ800);
WiFiClientSecure wifiClient;
PubSubClient mqttClient(wifiClient);
volatile bool everTouched = false;
volatile bool ntpComplete = false;
volatile bool inboundGlow = false;

const char mqttGlowTopic[] = "/devices/glow";
const char mqttAnnounceTopic[] = "/devices/announce";
enum { CMD_NONE, CMD_WEDDING_FIREWORKS, CMD_DEPROVISION, CMD_PROVISION };

void LedGlideBlocking(unsigned long duration, int r1, int g1, int b1);
void LedRotate(unsigned long speed, int r, int g, int b);
void LedPulse(unsigned long speed, int r, int g, int b);
bool EverTouched();

const int brownr = 0x96/3, browng = 0x4b/3, brownb = 0/3;  // brownish

class MyWiFiManager : public WiFiManager
{
  public:
    virtual bool OnWaitForSSIDConnect() const;
    virtual bool OnWaitForURLConnect() const;
    virtual void OnConnecting() const;
};

void setup()
{
  static MyWiFiManager wifimgr;

  Serial.begin(115200);

  double voltage = GetBatteryVoltage(BATTERYPIN);
  if (voltage < 3.5)
  {
    RenderVoltage(voltage);
  }
  else
  {
    unsigned long startmillis = millis();
    pinMode(LEDPIN, OUTPUT);

    pixels.begin();

    touchAttachInterrupt(TOUCHPIN, []() { everTouched = true; }, TOUCH_THRESHOLD);

    HandleStartup(wifimgr);

    unsigned long elapsed = millis() - startmillis;
    Serial.printf("Total time awake = %lu ms\n", elapsed);
  }

  DeepSleep(60000);
}

void loop() {}

/// @brief Handle general touch startup and two special cases if held a longer time
///        6 seconds = WiFi Training
///        20 seconds = Provision with default SSID
/// @param wifimgr
/// @return true if extended touch was handled
bool HandleSpecialTouchStartup(MyWiFiManager &wifimgr)
{
  if (!EverTouched())
    return false;
  
  unsigned long start = millis();
  LedGlideBlocking(1000, brownr, browng, brownb); // glide to brownish over 1 second
  Serial.printf("Touch startup!\n");

  // If user holds button for 6 seconds, this is a sign to enter WiFi training mode 
  while (CurrentlyTouched() && millis() - start < 6000);

  // Still touched after 6 seconds?
  if (CurrentlyTouched())
  {
    Serial.printf(" - still touched after 6 seconds\n");
    LedGlideBlocking(2000, 0, 0, 255);  // Glide to blue

    // If still holding after 20 seconds, auto-provision with default SSID/password instead
    while (CurrentlyTouched() && millis() - start < 20000);

    // Still touched after 20 seconds?
    if (CurrentlyTouched()) // Provision if still touched after 20 seconds
    {
      Serial.printf(" - still touched after 20 seconds: Provision!\n");
      Provision(wifimgr);
    }
    else // Gather credentials (touched > 6 but < 20 seconds)
    {
      Serial.printf(" - WiFi training mode\n");
      WiFi.scanNetworks(true);
      int networksFound;
      while ((networksFound = WiFi.scanComplete()) < 0)
        LedPulse(1000, 0, 0, 255);  // Blue pulsing
      wifimgr.GatherCredentials(WIFI_HOST_NAME, ACK_PAGE_TITLE, ACK_MESSAGE);
    }
    LedGlideBlocking(1000, brownr, browng, brownb); // glide back to brownish over 1 second
    return true;
  }
  return false;
}

/// @brief Decide what to do on startup.  Depends on whether start was triggered by timer or touch
/// @param wifimgr
/// @return void
void HandleStartup(MyWiFiManager &wifimgr)
{
  // Was it a touch wakeup?
  esp_sleep_wakeup_cause_t wakeup_reason = esp_sleep_get_wakeup_cause();
  if (wakeup_reason == ESP_SLEEP_WAKEUP_TOUCHPAD || CurrentlyTouched())
    everTouched = true;
  
  // Quick green flash indicates a true restart (should be rare)
  if (wakeup_reason == ESP_SLEEP_WAKEUP_UNDEFINED)
  {
    LedGlideBlocking(500, 0, 255, 0);
    LedGlideBlocking(500, 0, 0, 0);
    Serial.printf("Welcome to the Wedding Puck\n");
    Serial.printf(" - Initial startup\n");
  }

  // Get the system clock.  What time did we wake up?
  time_t now = time(NULL);
  struct tm tmWakeup;
  localtime_r(&now, &tmWakeup);

  // Handle startup that happens from touch
  bool specialTouchHandled = HandleSpecialTouchStartup(wifimgr);

  if (!specialTouchHandled)
  {
    // Every year on the anniversary, do an all-day celebration!
#if defined(WEDDING_DAY) && defined(WEDDING_MONTH) && defined(WEDDING_YEAR)
    if (tmWakeup.tm_mday == WEDDING_DAY && tmWakeup.tm_mon + 1 == WEDDING_MONTH && tmWakeup.tm_year + 1900 > WEDDING_YEAR)
      AnniversaryFireworks();
#endif
    // Try to connect to the configured WiFi
    if (wifimgr.Connect())
    {
      // Test if we need to resync our clock with NTP servers (at initial startup or every 24 hours)
      bool waitForNTPCompletion = InitiatedNTPSync(tmWakeup);

      TryConnectMQTT(wifimgr, wakeup_reason);

      // Try to initiate a glow?
      Serial.printf("Try to initiate glow? %s\n", EverTouched() ? "Yes" : "No");
      bool initiateGlow = EverTouched() && TryInitiateGlow(wifimgr);
      Serial.printf(" - Initiated glow? %s\n", initiateGlow ? "Yes!" : EverTouched() ? "No, not permitted" : "No, not applicable");

      // Check for new subscriber messages to possibly set inboundGlow from inbound message
      Serial.printf("Checking for MQTT subscriber messages...\n");
      for (unsigned long start=millis(); millis() - start < 2000; )
        mqttClient.loop();

      // Check to see if we should do a glow
      Serial.printf("Need to perform glow? %s\n", inboundGlow || initiateGlow ? "Yes" : "No");
      if (inboundGlow || initiateGlow)
      {
        inboundGlow = false;
        LedGlideBlocking(1000, 255, 255, 255);
        WeddingFireworks(FIREWORKS_LENGTH_SECONDS);
      }

      // If we need to wait for the NTP process to complete, do it here
      if (waitForNTPCompletion)
      {
        if (!ntpComplete)
          Serial.printf("Waiting for NTP sync...\n");
        for (unsigned long start = millis(); !ntpComplete && millis() - start < 30000; )
          ;
      }
    }

    else // if Connect failed, it's usually because there is no good WiFi SSID/password
    {
      if (EverTouched())  // signal this with a short purple "error" glow
        LedErrorPulse(2000, 255, 0, 255);
    }
  }

  if (AnyLedsOn())
    LedGlideBlocking(2000, 0, 0, 0);        // fade back to black
    

  // Step 2: Check for fancy SSID commands
  int nNetworksAvailable = WiFi.scanComplete();
  int cmd = GetSSIDCommand(nNetworksAvailable);

  switch (cmd)
  {
    case CMD_NONE:
    default:
      Serial.printf(" - No SSID command issued\n");
      break;

    case CMD_WEDDING_FIREWORKS:
      // Do wedding fireworks for 1 minute repeatedly until SSID no longer available
      LedGlideBlocking(1000, 255, 255, 255); 
      do 
      { 
        WeddingFireworks(60);
        nNetworksAvailable = WiFi.scanNetworks();
      } while (GetSSIDCommand(nNetworksAvailable) == CMD_WEDDING_FIREWORKS);
      Serial.printf(" - Wedding fireworks complete\n");
      LedGlideBlocking(2000, 0, 0, 0); // Glide back to black
      break;

    case CMD_DEPROVISION:
      Serial.printf(" - Provisioning\n");
      wifimgr.EraseCredentials();
      break;

    case CMD_PROVISION:
      Serial.printf(" - Provisioning\n");
      Provision(wifimgr);
      LedGlideBlocking(2000, 0, 0, 0); // Glide back to black
      break;
  }

  Serial.printf("The time is %d-%d-%04d %02d:%02d:%02d\n", 
    tmWakeup.tm_mday, tmWakeup.tm_mon + 1, tmWakeup.tm_year + 1900, tmWakeup.tm_hour, tmWakeup.tm_min, tmWakeup.tm_sec);
}

void MqttCallback(char *topic, byte *payload, unsigned int length) 
{
  String payloadStr = "";
  for (int i = 0; i < length; i++)
    payloadStr += (char)payload[i];

  Serial.printf("MQTT Message arrived [%s]\n - %s [NEW]\n", topic, payloadStr.c_str());
  String lastInboundGlowMessage = WiFiManager::ReadFile("/lastinbound");
  Serial.printf(" - %s [LAST]\n", lastInboundGlowMessage.c_str());
  
  // Is it a new message, i.e., should we glow?
  if (String(topic) == "/devices/glow" && lastInboundGlowMessage != payloadStr)
  {
      inboundGlow = true;
      WiFiManager::WriteFile("/lastinbound", payloadStr.c_str());
  }
}

/// @brief Scan the available WiFi SSIDs and see if any is a secret command
/// @param nNetworksAvailable - if you have already done a WiFi Scan, send a non-zero value here for number of networks found
/// @return CMD_NONE (0) if no secret command found, else the ID of the command

int GetSSIDCommand(int nNetworksAvailable)
{
  if (nNetworksAvailable == 0)
    nNetworksAvailable = WiFi.scanNetworks();

  Serial.printf("Looking for WiFi SSID commands\n");
  Serial.printf(" - %lu: %d WiFi networks detected.\n", millis(), nNetworksAvailable);
  struct { const char *name; int cmd;} table[] = 
  {
      FIREWORKS_SSID, CMD_WEDDING_FIREWORKS,
      DEPROVISION_SSID, CMD_DEPROVISION,
      PROVISION_SSID, CMD_PROVISION,
  };

  for (int i=0; i<nNetworksAvailable; ++i)
    for (int j=0; j<sizeof(table) / sizeof(table[0]); ++j)
      if (WiFi.SSID(i) == table[j].name)
      {
        Serial.printf(" - Command found: %s (%d)\n", table[j].name, table[j].cmd);
        return table[j].cmd;
      }
  return CMD_NONE;
}

void WeddingFireworks(int seconds)
{
  // from https://www.springtree.net/audio-visual-blog/rgb-led-color-mixing/
  static const uint8_t nicecolors[][3] = 
  {
    { 255, 255, 255 }, // white
    { 255, 150, 64 }, // orange
    { 80, 210, 255 }, // light blue
    { 255, 64, 255 }, // magenta
    { 64, 255, 96 }, // blue green
    { 255, 255, 64 }, // yellow
    { 230, 128, 128 }, // light pink
    { 128, 255, 64 },    // yellow green
  };
  int ncolors = sizeof(nicecolors) / sizeof(nicecolors[0]);
  int cur = 0;
  Serial.printf("Wedding Fireworks!\n");
  digitalWrite(LEDPIN, HIGH);
  for (unsigned long start = millis(); millis() - start < 1000UL * seconds; )
  {
    uint8_t r = nicecolors[cur][0];
    uint8_t g = nicecolors[cur][1];
    uint8_t b = nicecolors[cur][2];
    LedGlideBlocking(3000, r, g, b);
    cur = (cur + 1) % ncolors;
  }
  digitalWrite(LEDPIN, LOW);
  LedGlideBlocking(2000, 255, 255, 255);
}

void AnniversaryFireworks()
{
  static const uint8_t nicecolors[][3] = 
  {
    { 255, 255, 255 }, // white
    { 255, 150, 64 }, // orange
    { 80, 210, 255 }, // light blue
    { 255, 64, 255 }, // magenta
    { 64, 255, 96 }, // blue green
    { 255, 255, 64 }, // yellow
    { 230, 128, 128 }, // light pink
    { 128, 255, 64 },    // yellow green
  };
  int r[NUMPIXELS], g[NUMPIXELS], b[NUMPIXELS];
  int tabsize = sizeof(nicecolors) / sizeof(nicecolors[0]);
  int minutes = 24 * 60;
  Serial.printf(" - Anniversary Fireworks!\n");

  // Given current color, next color, and time, calculate all the pixels.
  unsigned long prev = millis();
  unsigned long now = millis();
  for (unsigned long start = now; now - start < 1000UL * 60UL * minutes; prev = now, now = millis())
  {
    // initialize
    int changerate = 2000;
    int index = (now / changerate) % tabsize;
    int index2 = (index + 1) % tabsize;
    int n = now % changerate;
    double f = (double)n / changerate;
    for (int i=0; i<NUMPIXELS; ++i)
    {
      r[i] = (1-f) * nicecolors[index][0] + f * nicecolors[index2][0];
      g[i] = (1-f) * nicecolors[index][1] + f * nicecolors[index2][1];
      b[i] = (1-f) * nicecolors[index][2] + f * nicecolors[index2][2];
    }

    // Pulse and rotate/sparkle
    int pulserate = 4000;
    n = now % pulserate;
    double factor = 2 * n < pulserate ? 2.0 * n / pulserate : 2.0 * (pulserate - n - 1) / pulserate;
    factor = 0.2 + factor * 0.8;

    int rotatespeed = 100;
    int pixoff = (now / rotatespeed) % NUMPIXELS;
    for (int i=0; i<NUMPIXELS; i++)
    {
      double factor2 = pixoff == i || pixoff == (i + NUMPIXELS / 2) % NUMPIXELS ? 0.7 * factor : factor;
      r[i] = (int)(factor2 * r[i]);
      g[i] = (int)(factor2 * g[i]);
      b[i] = (int)(factor2 * b[i]);
    }

    for (int i=0; i<NUMPIXELS; ++i)
      pixels.setPixelColor(i, pixels.Color(r[i], g[i], b[i]));
    pixels.show();
  }
  LedGlideBlocking(2000, 255, 255, 255);
}

void RenderVoltage(float v)
{
  uint32_t color = 
    v < 3.5 ? pixels.Color(255, 0, 0) :    // red
    v < 3.6 ? pixels.Color(255, 0xA5, 0) : // orange
    v < 3.7 ? pixels.Color(255, 255, 0) :  // yellow
    v < 3.8 ? pixels.Color(255, 0, 255) :  // magenta
    v < 3.9 ? pixels.Color(0, 0, 255) :    // blue
    v < 4.0 ? pixels.Color(0, 255, 255) :  // cyan
    pixels.Color(0, 255, 0);               // green

    LedFlash(color, 250, 100);
}

double GetBatteryVoltage(int pin)
{
  uint32_t mV = readADC_Cal(analogRead(pin)) * 2 + readADC_Cal(analogRead(pin)) * 2 + readADC_Cal(analogRead(pin)) * 2;
  return (double)mV / 3000.0;
}

uint32_t readADC_Cal(int ADC_Raw)
{
    esp_adc_cal_characteristics_t adc_chars;

    esp_adc_cal_characterize(ADC_UNIT_1, ADC_ATTEN_DB_11, ADC_WIDTH_BIT_12, 1100, &adc_chars);
    return esp_adc_cal_raw_to_voltage(ADC_Raw, &adc_chars);
}

void DeepSleep(unsigned mSecs)
{
  digitalWrite(LEDPIN, LOW);
  uint64_t sleepUs = 1000 * (uint64_t)mSecs;
  Serial.printf("%lu: Sleeping for %lu milliseconds\r\n", millis(), mSecs);

#if false // This prevents sleep from happening properly!  Don't do it!
  Serial.flush();
  Serial.end();
#endif

  for (int i=0; i<NUMPIXELS; ++i)
    pixels.setPixelColor(i, pixels.Color(0, 0, 0));
  pixels.show();
  pinMode(NEOPIXELPIN, INPUT);

  WiFi.disconnect();
  WiFi.mode(WIFI_OFF);

  esp_sleep_enable_timer_wakeup(sleepUs);
  touchSleepWakeUpEnable(T5, TOUCH_THRESHOLD);
  esp_deep_sleep_start();
}

bool CurrentlyTouched()
{
  bool touched = touchRead(TOUCHPIN) >= TOUCH_THRESHOLD;
  if (touched)
    everTouched = true;
  return touched;
}

bool EverTouched() { return CurrentlyTouched() || everTouched; }

// Glow logic
bool TryInitiateGlow(MyWiFiManager &wifimgr)
{
  time_t now = time(NULL);
  String lastInitiationTimeString = WiFiManager::ReadFile("/lastoutbound");
  time_t lastInitiationTime = lastInitiationTimeString.toInt();
  Serial.printf(" - Last Init was %ld, current time is %ld\n", lastInitiationTime, now);
  if (now - lastInitiationTime >= SECONDS_BETWEEN_GLOWS)
  {
    WiFiManager::WriteFile("/lastoutbound", String(now).c_str());
    mqttClient.publish(mqttGlowTopic, ConstructMQTTMessage(wifimgr).c_str(), true);
    return true;
  }

  LedErrorPulse(2000, 255, 0, 0);         // A red error indicator
  return false;
}

String ConstructMQTTMessage(WiFiManager &wifimgr)
{
  return String("{ \"MAC\": \"") + WiFi.macAddress() + "\", \"owner\": \"" + wifimgr.GetOwner() + "\", \"timestamp\": \"" + time(NULL) + "\"}";
}

bool TryConnectMQTT(WiFiManager &wifimgr, esp_sleep_wakeup_cause_t wakeup_reason)
{
  wifiClient.setInsecure();
  mqttClient.setServer(mqttServer, 8883);
  mqttClient.setCallback(MqttCallback);

  for (unsigned long start = millis(); millis() - start < 30000 && !mqttClient.connected(); )
  {
    // Create a random client ID
    String clientId = "ESP32Client-";
    clientId += WiFi.macAddress();

    // Attempt to connect
    bool cleanSession = wakeup_reason == ESP_SLEEP_WAKEUP_UNDEFINED;
    Serial.printf("Attempting MQTT connection (%s session) with device %s...", cleanSession ? "clean" : "dirty", clientId.c_str());
    if (mqttClient.connect(clientId.c_str(), mqttUser, mqttPass)) 
    {
      Serial.printf("connected!\n");

      // First time connected, publish an announcement...
      if (esp_sleep_get_wakeup_cause() == ESP_SLEEP_WAKEUP_UNDEFINED)
      {
        Serial.printf("Publishing to topic %s\n", mqttAnnounceTopic);
        mqttClient.publish(mqttAnnounceTopic, ConstructMQTTMessage(wifimgr).c_str(), true);
      }

      // ... and resubscribe
      Serial.printf(" - subscribing to topic %s\n", mqttGlowTopic);
      mqttClient.subscribe(mqttGlowTopic, 1);
    } 
    else 
    {
      Serial.printf("failed, rc=%d, try again in 5 seconds\n", mqttClient.state());

      // Wait 5 seconds before retrying
      delay(5000);
    }
  }
  return mqttClient.connected();
}

// NTP Time-related functions
void OnNTPTimeAvailable(struct timeval *t)
{
    struct tm tmLocal;
    if (!getLocalTime(&tmLocal))
      log_e("What? No time available?\n");
    else
      Serial.printf("Got time adjustment from NTP: %d-%d-%04d %02d:%02d:%02d\n", 
        tmLocal.tm_mday, tmLocal.tm_mon + 1, tmLocal.tm_year + 1900, tmLocal.tm_hour, tmLocal.tm_min, tmLocal.tm_sec);
    ntpComplete = true;
}

bool InitiatedNTPSync(const struct tm &tm)
{
  // Every night at midnight (or at first startup) do NTP sync
  if (esp_sleep_get_wakeup_cause() == ESP_SLEEP_WAKEUP_UNDEFINED ||
    (tm.tm_hour == 0 && (tm.tm_min == 0 || tm.tm_min == 1)) || 
    tm.tm_year + 1900 <= 1970)
  {
    static const char ntpServer1[] = "pool.ntp.org";
    static const char ntpServer2[] = "time.nist.gov";

    // set notification call-back function
    sntp_set_time_sync_notification_cb(OnNTPTimeAvailable);

    /**
     * NTP server address could be acquired via DHCP,
     *
     * NOTE: This call should be made BEFORE esp32 aquires IP address via DHCP,
     * otherwise SNTP option 42 would be rejected by default.
     * NOTE: configTime() function call if made AFTER DHCP-client run
     * will OVERRIDE aquired NTP server address
     */
    sntp_servermode_dhcp(1);    // (optional)

    configTime(0, 0, ntpServer1, ntpServer2);
    return true;
  }
  return false;
}

// Commands from "Special" SSIDs
void Provision(MyWiFiManager &wifimgr)
{
  LedGlideBlocking(2000, 0, 255, 0);  // Glide to green
#if defined(DEFAULT_WIFI_SSID) && defined(DEFAULT_WIFI_PASS) && defined(DEFAULT_WIFI_OWNER)
  wifimgr.ProvisionCredentials(DEFAULT_WIFI_SSID, DEFAULT_WIFI_PASS, DEFAULT_WIFI_OWNER);
#endif
  delay(2000);
}

// LED manipulation
void LedErrorPulse(int duration, int r, int g, int b)
{
  int speed = 1000;
  LedGlideBlocking(500, r, g, b);     // glide to that color
  for (unsigned long start = millis(); millis() - start < duration; )
  {
    LedGlideBlocking(speed / 2, r / 2, g / 2, b / 2);
    LedGlideBlocking(speed / 2, r, g, b);
  }
}

bool AnyLedsOn()
{
  for (int i=0; i<NUMPIXELS; ++i)
    if (pixels.getPixelColor(i) != 0)
      return true;
  return false;
}

void LedFlash(uint32_t color, unsigned long duration, unsigned long after)
{
  int r = (color >> 16) & 0xFF;
  int g = (color >> 8) & 0xFF;
  int b = (color >> 0) & 0xFF;
  LedGlideBlocking(100, r, g, b);
  if (duration > 200)
    delay(duration - 200);
  LedGlideBlocking(100, 0, 0, 0);
  delay(after);
}

// An instantaneous function
void LedRotate(unsigned long speed, int r, int g, int b)
{
  unsigned long t = millis() % speed;
  int whichpixel = t * NUMPIXELS / speed;
  int whichpixel2 = (whichpixel + 4) % NUMPIXELS;
  for (int i=0; i<NUMPIXELS; ++i)
    pixels.setPixelColor(i, i == whichpixel || i == whichpixel2 ? pixels.Color(r, g, b) : pixels.Color(r / 2, g / 2, b / 2));
  pixels.show();
}

// Another instantaneous function
void LedPulse(unsigned long speed, int r, int g, int b)
{
  double t = (millis() % speed) * 2 * PI / speed;
  double factor = 0.75 + sin(t) / 4; // between 0.5 and 1.0
  for (int i=0; i<NUMPIXELS; ++i)
    pixels.setPixelColor(i, pixels.Color((int)(factor * r), (int)(factor * g), (int)(factor * b)));
  pixels.show();
}

void LedRotateBlocking(unsigned long duration, unsigned long speed, int r, int g, int b)
{
    for (unsigned long start = millis(); millis() - start < duration; )
      LedRotate(speed, r, g, b);
}
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
